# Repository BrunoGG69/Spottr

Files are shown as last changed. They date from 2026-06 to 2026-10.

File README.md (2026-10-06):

<p align="center">
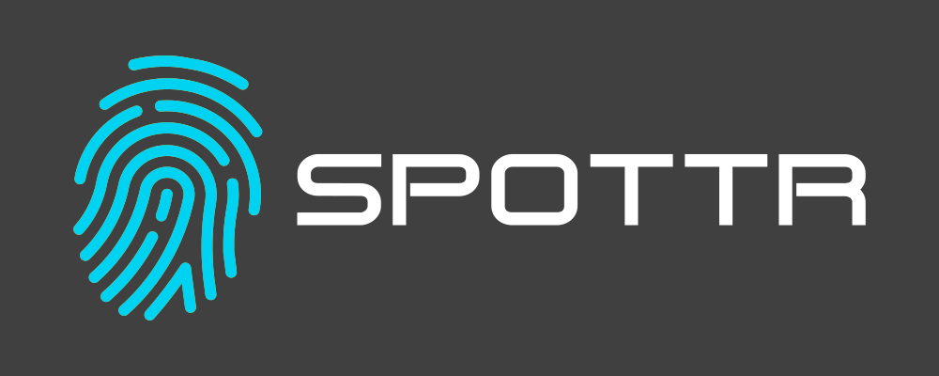
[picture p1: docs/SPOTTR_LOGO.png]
Spottr Logo
  
</p>

# SPOTTR: Real-time BLE Presence Tracking using ESP32

SPOTTR is an open-source indoor presence tracking system built on a cheap aah microcontroller (ESP32-C3 & ESP32-C6) and Bluetooth Low Energy. This project has multiple applications as it can be used in schools, offices, warehouses or even hospitals.

<p align="center">
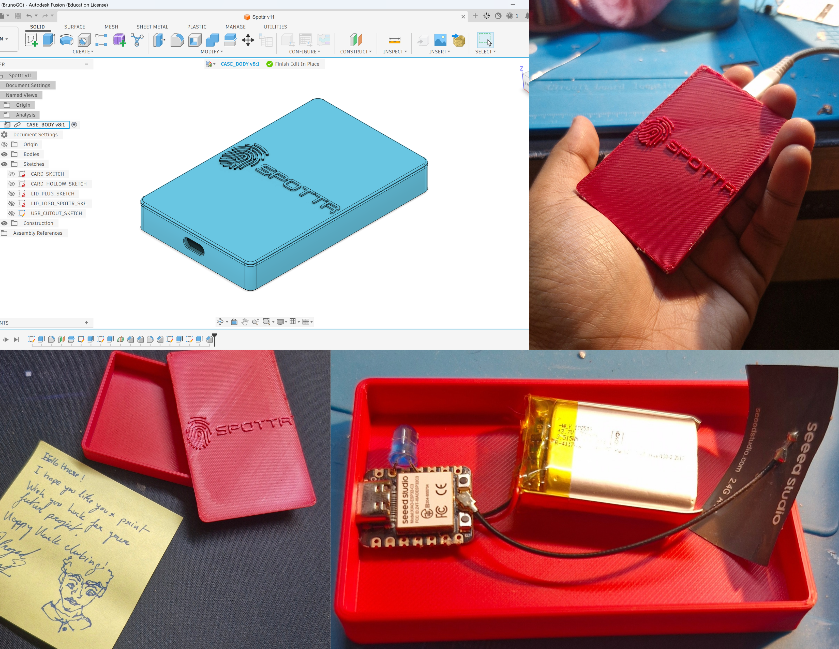
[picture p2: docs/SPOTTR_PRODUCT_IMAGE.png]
  
</p>

---

## Features

- **Wearable BLE Badges**: ESP32-C3 Powered badges that broadcast BLE signals at a particular period of time.
- **Room Level Detection**: Fixed scanner nodes placed in every room to detect the badges and publish the recieved values via MQTT.
- **Spottr-Bridge**: This is a server that sits between the scanner-nodes and the cloud as data from the nodes first reaches this server via MQTT and then passed on to the cloud. Did this to reduce load on each scanner if they started publishing data individually.

---

## Hardware Components Used

- **ESP32-C3**: A Low-power microcontroller which also has BLE support. This is used inside the badges
- **LiPo Battery**: To power the badge.
- **ESP32-C6**: Used in the scanner-nodes to recieve data from ESP32-C3 badges.

---

## Renders

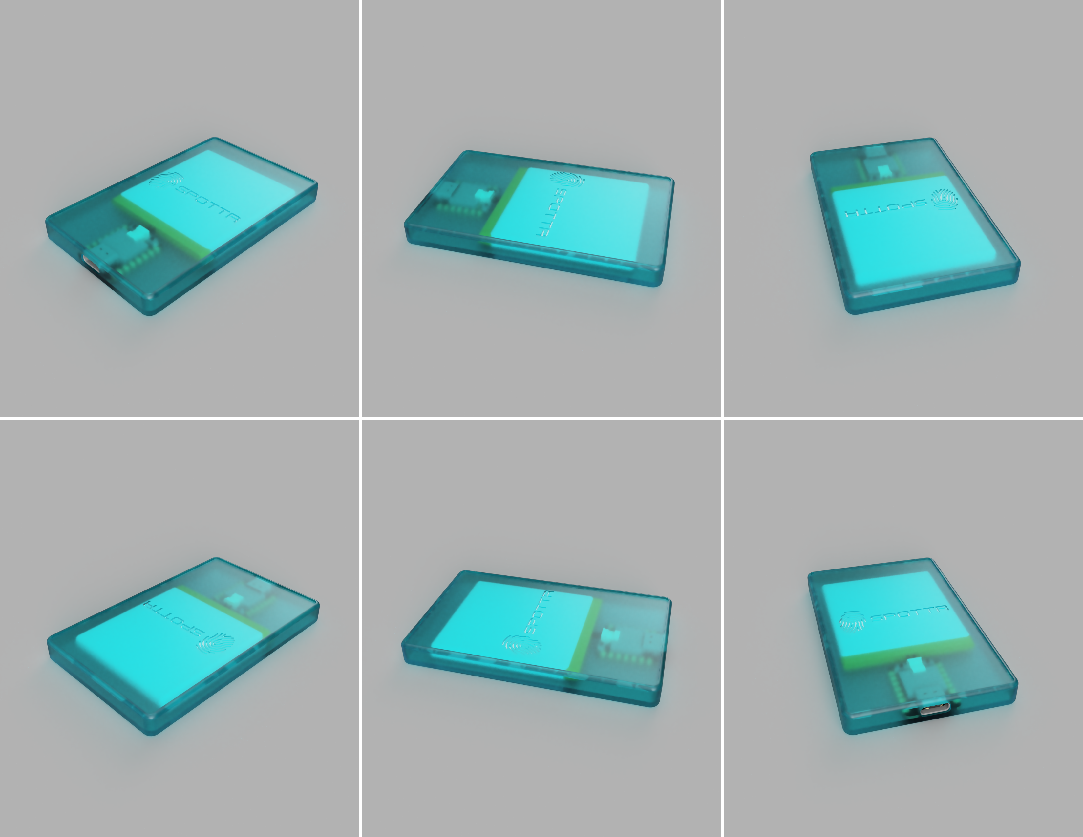
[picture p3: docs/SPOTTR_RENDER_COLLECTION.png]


---

## Wiring Diagram

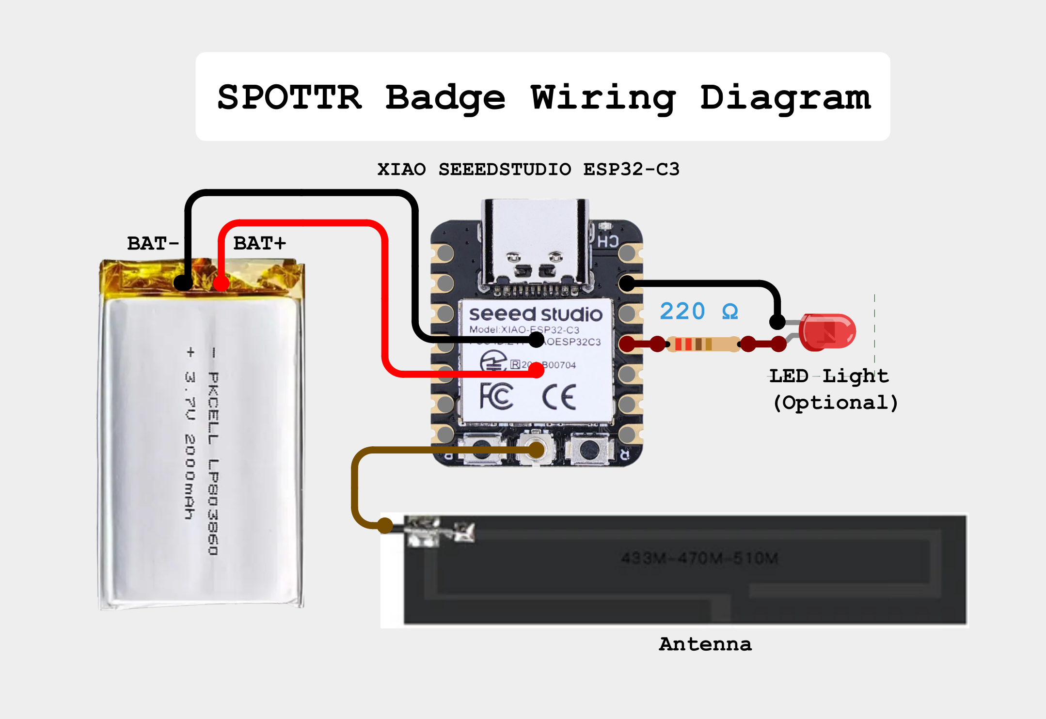
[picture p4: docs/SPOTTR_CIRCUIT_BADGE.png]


---

## Flow Chart

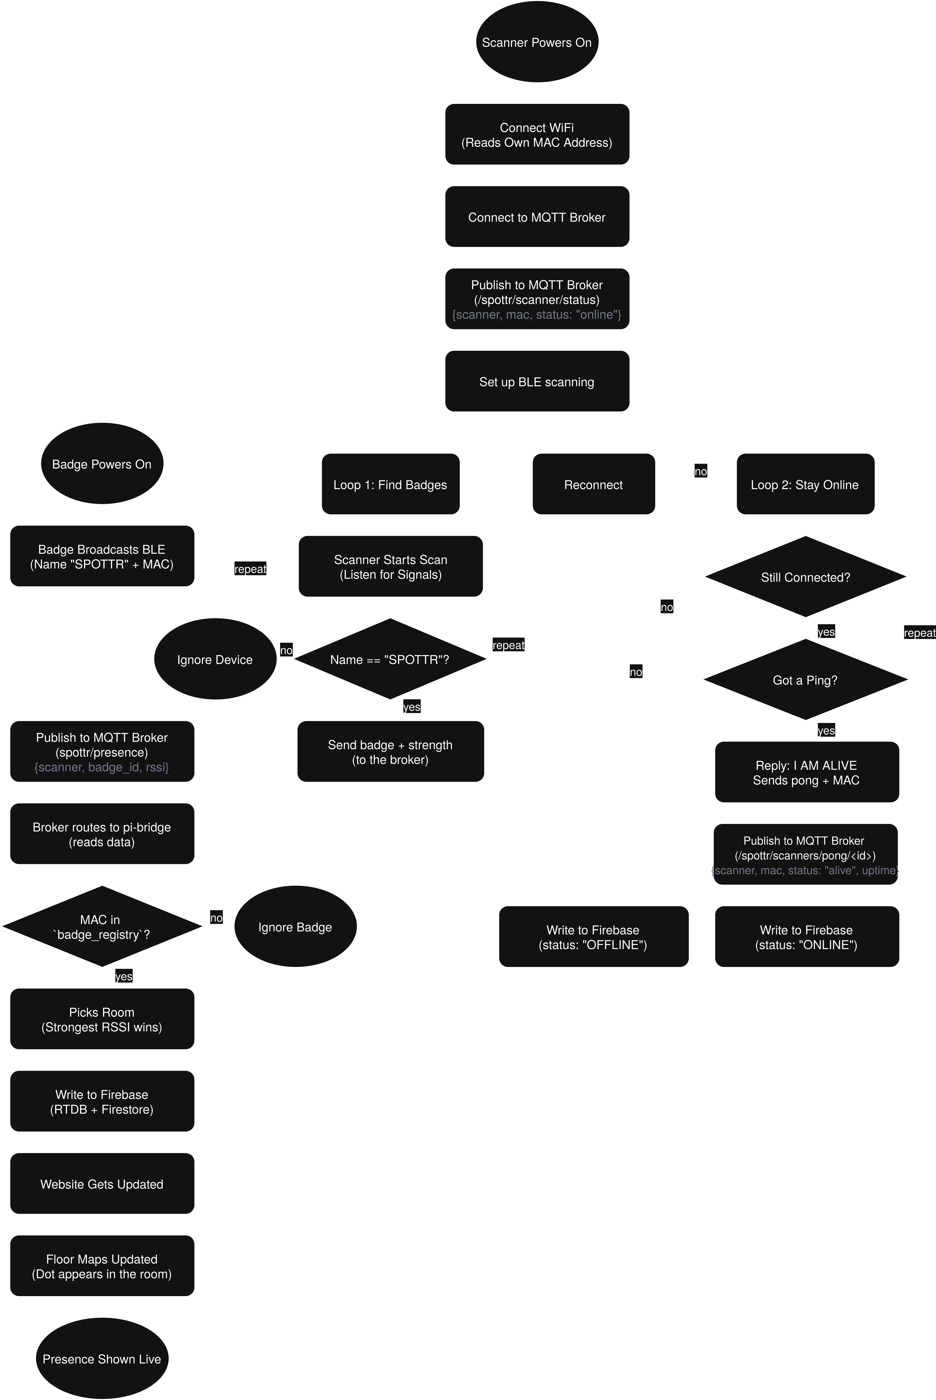
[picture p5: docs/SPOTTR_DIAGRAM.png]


---

## Setup Guide:

Checkout the [Setup File](SETUP_PROJECT.md)

---

## License

AGPL-3.0 © 2026 Prathamesh Prabhakar

---

> **Note: Spottr is currently under active development. Stay tuned for more stuff to be added**

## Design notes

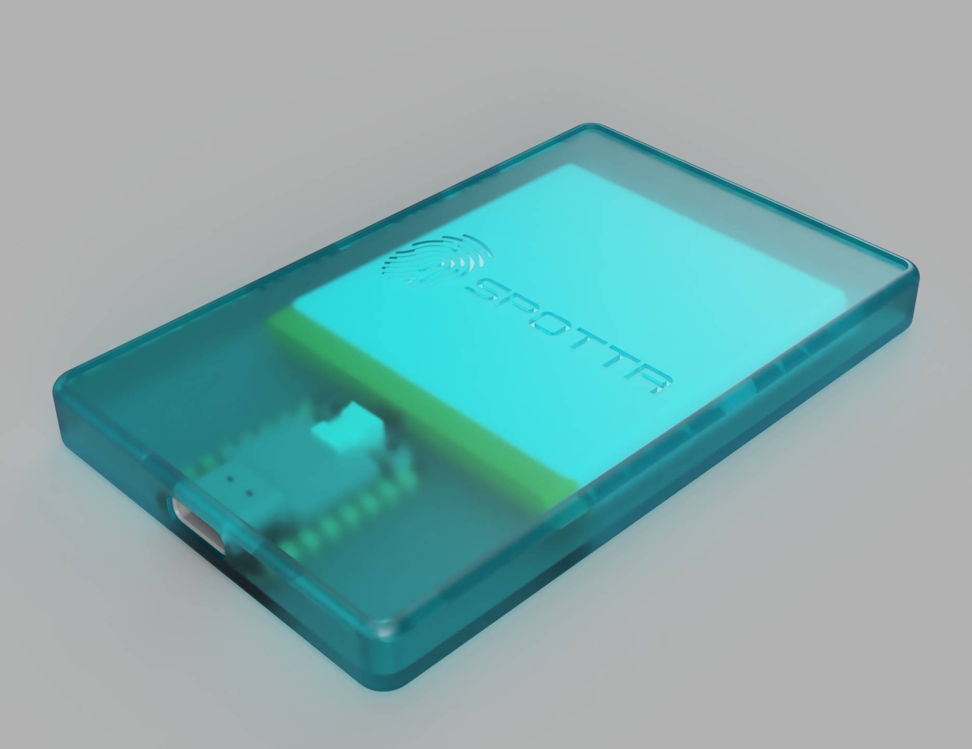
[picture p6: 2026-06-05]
docs/SPOTTR_RENDER_1 - Copy.png

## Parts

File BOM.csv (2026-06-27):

Item Name | Qty | Price (total) (USD) | Price (total) (INR) | Item link | Notes
ESP32-C6 | 2 | 12.18 | 1150 | https://techiesms.com/product/seeed-studio-xiao-esp32c6/ | Used for scanner nodes
ESP32-C3 | 2 | 11.86 | 1120 | https://techiesms.com/product/seeed-studio-xiao-esp32c3/ | Used for badges
Li-PO Battery | 2 | 6.64 | 628 | https://robu.in/product/nova-103450-2000mah-3-7v-lipo-battery-pack/ | Used in badges
Total Price: (USD) | 30.68
Total Price: (INR) | 2898

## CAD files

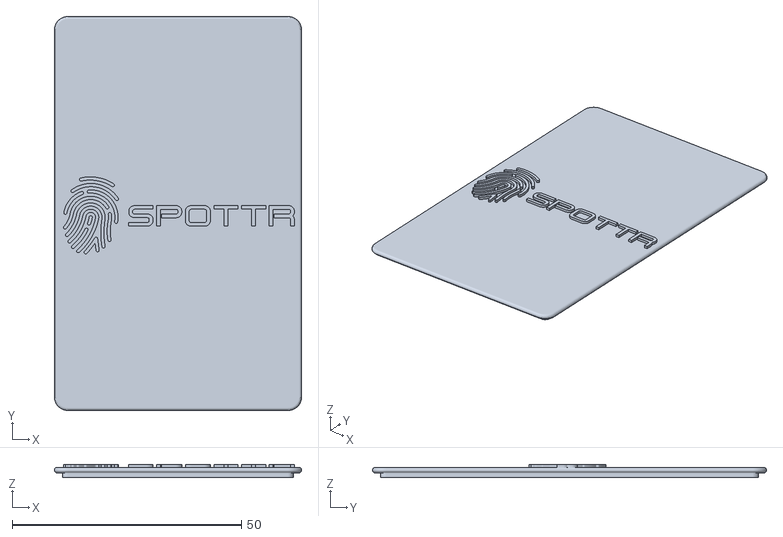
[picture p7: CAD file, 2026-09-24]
hardware/3d_print_files/SPOTTR_TOP_LID_STL.stl
54.0 x 86.0 x 2.80

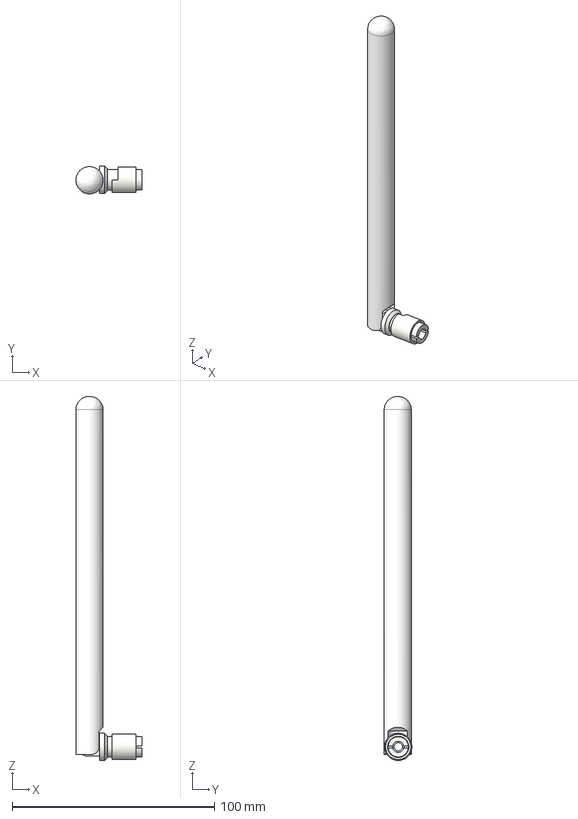
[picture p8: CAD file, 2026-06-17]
hardware/cad/Antenna.step
32.8 x 13.7 x 180.0 mm
Antenna Connector part
Main Antenna Part
Antenna Rollable Part

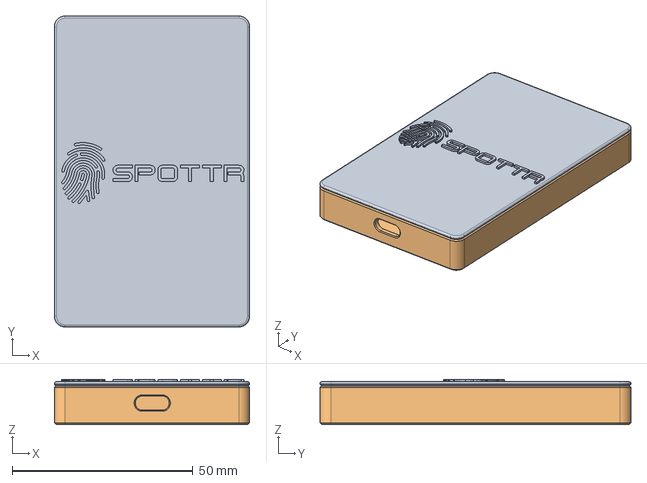
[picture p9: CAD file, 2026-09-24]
hardware/3d_print_files/Spottr.step
54.0 x 86.0 x 12.5 mm

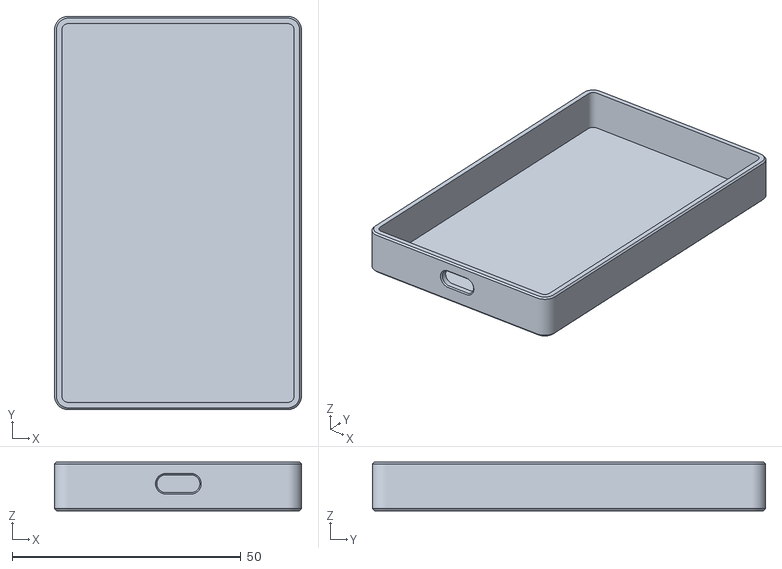
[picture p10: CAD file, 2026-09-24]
hardware/3d_print_files/SPOTTR_CARD_BODY_STL.stl
54.0 x 86.0 x 10.7

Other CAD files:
hardware/3d_print_files/Spottr.f3z
hardware/cad/Antenna.f3z
hardware/cad/Spottr.f3z
hardware/cad/Spottr.step

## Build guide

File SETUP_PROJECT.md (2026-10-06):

## Getting Started

### Prerequisites
- **ESP32-C3** modules for badges
- **ESP32-C6** modules for scanners
- **Any Linux server** (I would recommend running it locally)
- [PlatformIO](https://platformio.org/) on a PC

### 1. Flash the firmware
clone the repo and build the firmware using [PlatformIO](https://platformio.org/)
```bash
#badge
cd backend/firmware/badge/spottr-badge
pio run -t upload
```

```bash
#scanner
cd backend/firmware/scanner/spottr-scanner
pio run -t upload
```

### 2. Set up the Bridge
1. Install the Mosquitto MQTT broker on any server:
```bash
sudo apt update
sudo apt install mosquitto mosquitto-clients
sudo systemctl enable mosquitto
```
2. Set up the Python Bridge:
```bash
cd backend/pi-bridge
pip install -r requirements.txt
```
3. Create a `.env` file in `pi-bridge/` with the following variables:
```
FIREBASE_DB_URL='<RTDB URL>'
SERVICE_ACCOUNT='<PATH TO SERVICE ACCOUNT JSON FILE>'
```
4. Drop your Firebase Admin `serviceAccount.json` in the folder, then run:

```bash
python main.py
```

### 3. Run the Web Dashboard
```bash
cd frontend/website
npm install
npm run dev
```
Add your Firebase config to `.env` file. Check `.env.example` for your reference.

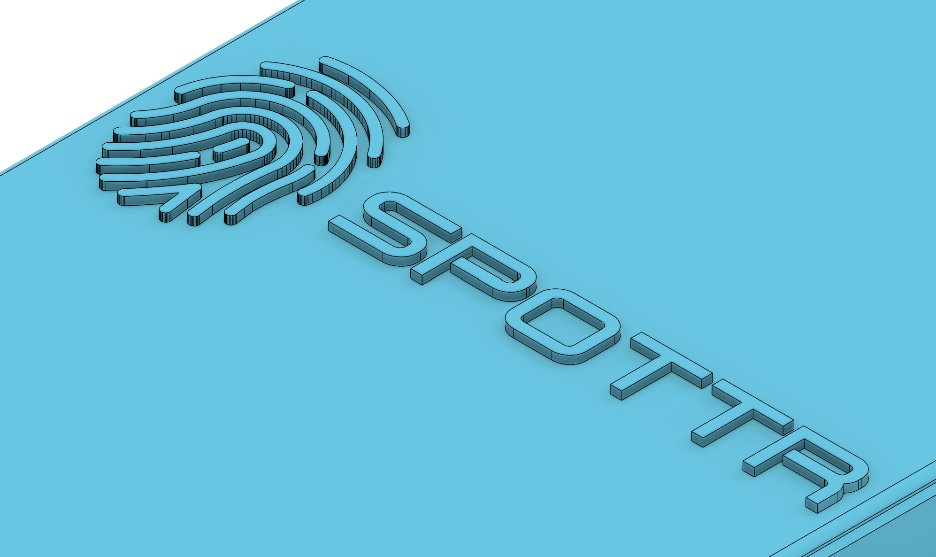
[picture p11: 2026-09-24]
hardware/3d_print_files/spottr_3d-print_3.png

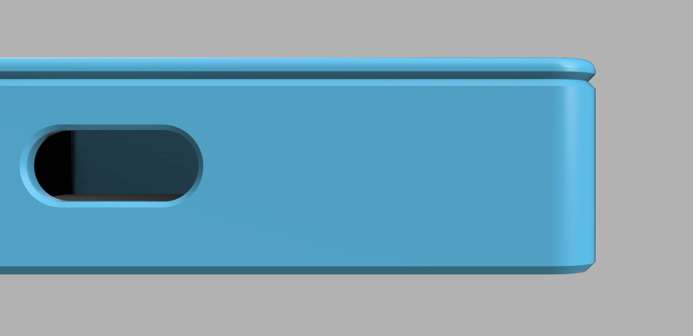
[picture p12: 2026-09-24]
hardware/3d_print_files/spottr_3d-print_2.png

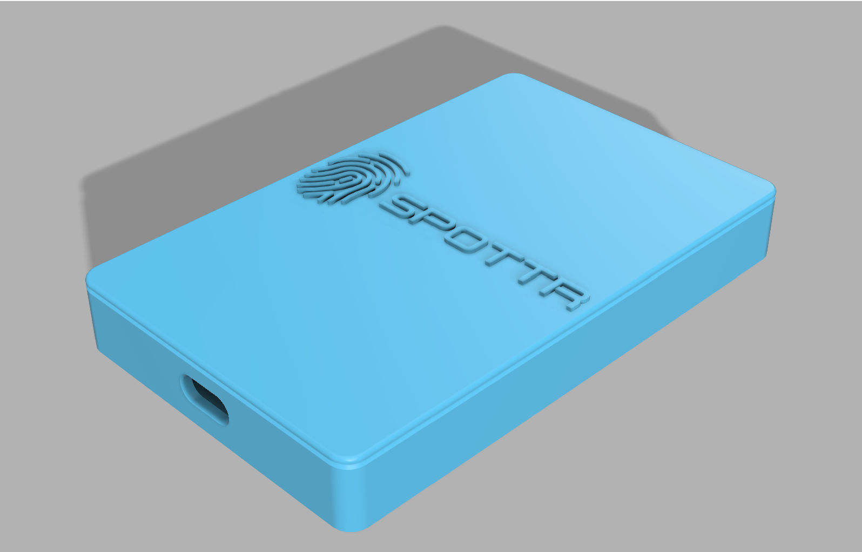
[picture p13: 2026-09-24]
hardware/3d_print_files/spottr_3d-print_1.png

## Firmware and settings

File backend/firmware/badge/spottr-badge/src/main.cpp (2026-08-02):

#include <Arduino.h>
#include <NimBLEDevice.h>

#define BADGE_ID "SPOTTR"

#define LED_PIN 10
#define LED_ACTIVE_LOW false
#define BLINK_INTERVAL 500

NimBLEAdvertising *adv;
static bool advertising = false;

static void ledWrite(bool on)
{
    digitalWrite(LED_PIN, (on != LED_ACTIVE_LOW) ? HIGH : LOW);
}

void setup()
{
    Serial.begin(115200);
    delay(200);

    pinMode(LED_PIN, OUTPUT);
    ledWrite(false);

    Serial.println();
    Serial.println("Spottr Badge booting...");

    NimBLEDevice::init(BADGE_ID);

    String mac = NimBLEDevice::getAddress().toString().c_str();
    Serial.println("Badge MAC: " + mac);

    NimBLEAdvertisementData advData;
    advData.setName(BADGE_ID);

    adv = NimBLEDevice::getAdvertising();
    adv->setAdvertisementData(advData);
    adv->start();

    advertising = true;
    Serial.println("Advertising as " BADGE_ID);
}

void loop()
{
    static unsigned long lastBlink = 0;
    static bool ledOn = false;

    if (advertising && millis() - lastBlink >= BLINK_INTERVAL)
    {
        lastBlink = millis();
        ledOn = !ledOn;
        ledWrite(ledOn);
    }
}

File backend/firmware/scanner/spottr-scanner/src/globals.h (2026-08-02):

#pragma once
#include <Arduino.h>
#include <WiFi.h>
#include <WebServer.h>
#include <DNSServer.h>
#include <Preferences.h>
#include <PubSubClient.h>
#include <NimBLEDevice.h>

#define DEFAULT_SCANNER_ID "scanner_node"
#define DEFAULT_MQTT_BROKER "192.168.0.12"
#define DEFAULT_MQTT_PORT 1883
#define DEFAULT_MQTT_USER ""
#define DEFAULT_MQTT_PASS ""

#define FW_MAJOR 0
#define FW_MINOR 8
#define FW_PATCH 1
#define FIRMWARE_VERSION "0.8.1"

extern PubSubClient mqtt;
extern Preferences preferences;
extern WebServer portalServer;
extern DNSServer dnsServer;
extern NimBLEScan *pBLEScan;

extern String scannerMac;
extern String scannerId;
extern String roomName;
extern String wifiSsid;
extern String wifiPass;
extern String mqttBroker;
extern uint16_t mqttPort;
extern String mqttUser;
extern String mqttPass;
extern uint8_t setupStep;
extern bool setupDone;
extern bool configPortalActive;

extern const byte DNS_PORT;
extern IPAddress apIP;

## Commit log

2026-06-05 feat: landing page hero, 3D badge model, sections scaffold, docs assets
2026-06-17 feat: changed pi-bridge script to use mac address to identify badges, started work on dashboard with overview section work started, sidebar drawer created using daisyUI. Added hardware files includin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
    [Antenna.f3z, Antenna.step, BOM.csv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]
2026-06-19 feat: changed floor map with traced room polygon. Restructure Dashboard layout, used daisyUI for statCards now
2026-06-25 docs: Updated README.md to include flowchart
2026-06-27 docs: Added BOM.csv to root
    [BOM.csv]
2026-07-17 feat: added status LEDs on the scanner so its state can be read at a glance without a serial monitor
2026-07-20 fix: implemented password authentication for mqtt + fixed captive portal bug where wifi name was same across all scanners
    [config.cpp, globals.h, main.cpp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]
2026-08-02 fix: fixed bugs in scanner nodes, improved light sequences
    [globals.h, main.cpp, ota.cpp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]
2026-08-16 docs: Added wiring diagram for the Spottr Badge
2026-08-16 docs: add circuit diagram for badge as a png file
2026-08-16 docs: Added wiring diagram of badge to README.md
2026-09-24 addition: added 3d printable files for Spottr case
    [BOM.csv, SPOTTR_CARD_BODY_STL.stl, SPOTTR_TOP_LID_STL.stl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]
2026-10-06 docs: moved BOM.csv to hardware folder
    [BOM.csv]
2026-10-22 docs: added step files, edited BOM.csv, edited README.md and updated the 3D models
2026-10-30 cad: put stl files in stl-files folder
